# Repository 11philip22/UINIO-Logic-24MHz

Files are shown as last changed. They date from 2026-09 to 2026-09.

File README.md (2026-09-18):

# UINIO-Logic-24MHz Logic Analyzer

[**UINIO-Logic-24MHz**](https://gitee.com/uinika/UINIO-Logic-24MHz) is a logic analyzer circuit design based on Infineon's (formerly Cypress) [**CY7C68013A**](https://www.infineon.com/cms/en/product/universal-serial-bus-usb-power-delivery-controller/peripheral-controllers/ez-usb-fx2lp/cy7c68013a-56ltxit/) `USB 2.0` controller and the [**sigrok**](https://sigrok.org/) open-source firmware. It provides a `24 MHz` sampling rate and **8** input channels.

| Front | Back |
| :---: | :---: |
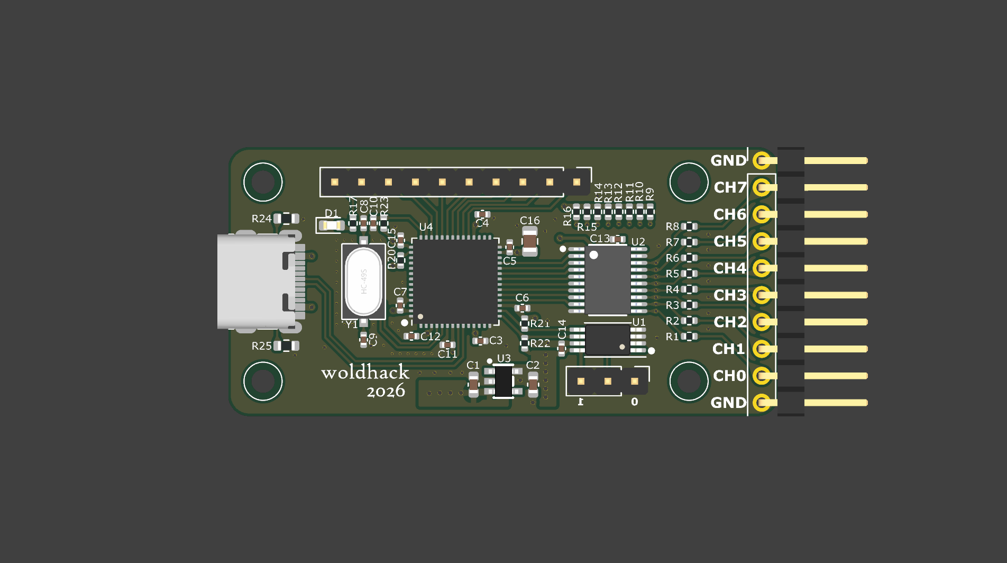
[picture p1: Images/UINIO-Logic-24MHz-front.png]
Front of the UINIO-Logic-24MHz PCB
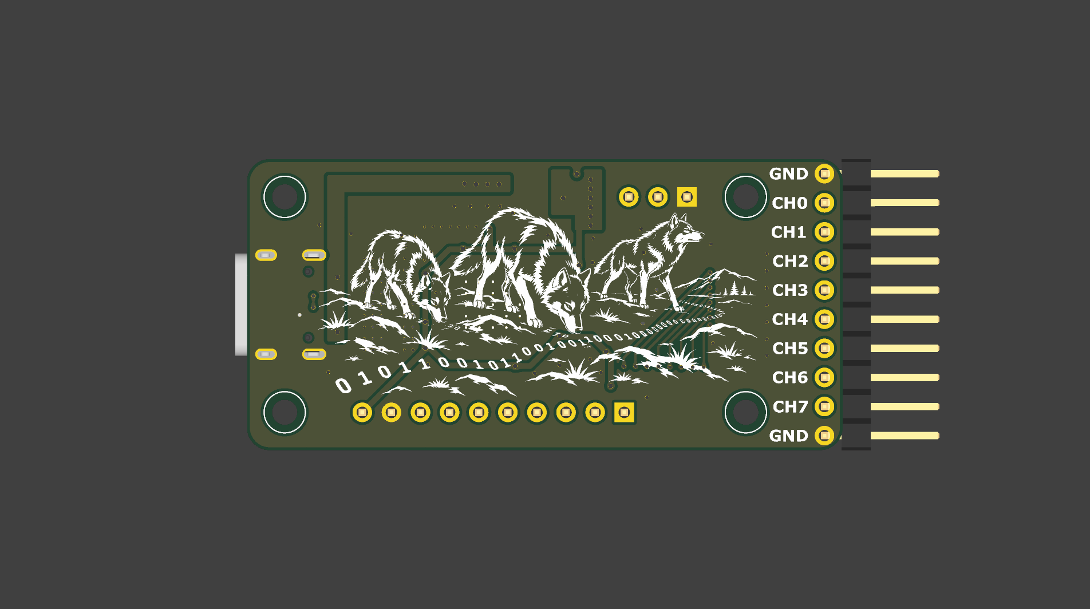
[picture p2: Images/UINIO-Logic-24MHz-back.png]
Back of the UINIO-Logic-24MHz PCB
|  |  |

## Design Overview

1. Uses a **USB Type-C** connector and a `10-pin` shrouded header.
2. The **CY7C68013A** USB controller uses a compact `QFN-56` package.
3. The **AT24C64** EEPROM from Microchip uses a compact `TSSOP-8` package.
4. Includes an onboard `24 MHz` passive SMD crystal; all SMD resistors and capacitors use the compact `0402` package.
5. Adds a **74HC245** eight-channel bus transceiver with **tri-state outputs** for more reliable signal acquisition.
6. The low-dropout regulator can use an **LDO** such as the `ME6211C33M5G` or `A6303AE5R-33A` in an `SOT-23-5` package.
7. Adds a set of TVS diodes for transient-voltage protection at the **USB Type-C** connector.

## Notes

- LED `D2` is connected to the **CY7C68013A** `PA0` pin, while `D3` is connected to `PA1`.
- Use the [sigrok-firmware-fx2lafw](https://github.com/wuxx/sigrok-firmware-fx2lafw) open-source firmware with the [PulseView](https://sigrok.org/wiki/Downloads) desktop application.

## Technical Documentation

[UinIO.com Electronics Technology Lab](http://uinio.com/) provides the following technical resources for the open-source **UINIO-Logic-24MHz** project:

- [UINIO-Logic-24MHz Core Board Schematic](http://uinio.com/my/works/UINIO-Logic-24MHz/UINIO-Logic-24MHz-Schematic.pdf)
- [Interactive BOM and PCB Layout Preview](http://uinio.com/archives/BOM/UINIO-Logic-24MHz.html)
- [UINIO-Logic-24MHz Logic Analyzer Quick Start Guide](http://uinio.com/Project/UINIO-Logic-24MHz/)

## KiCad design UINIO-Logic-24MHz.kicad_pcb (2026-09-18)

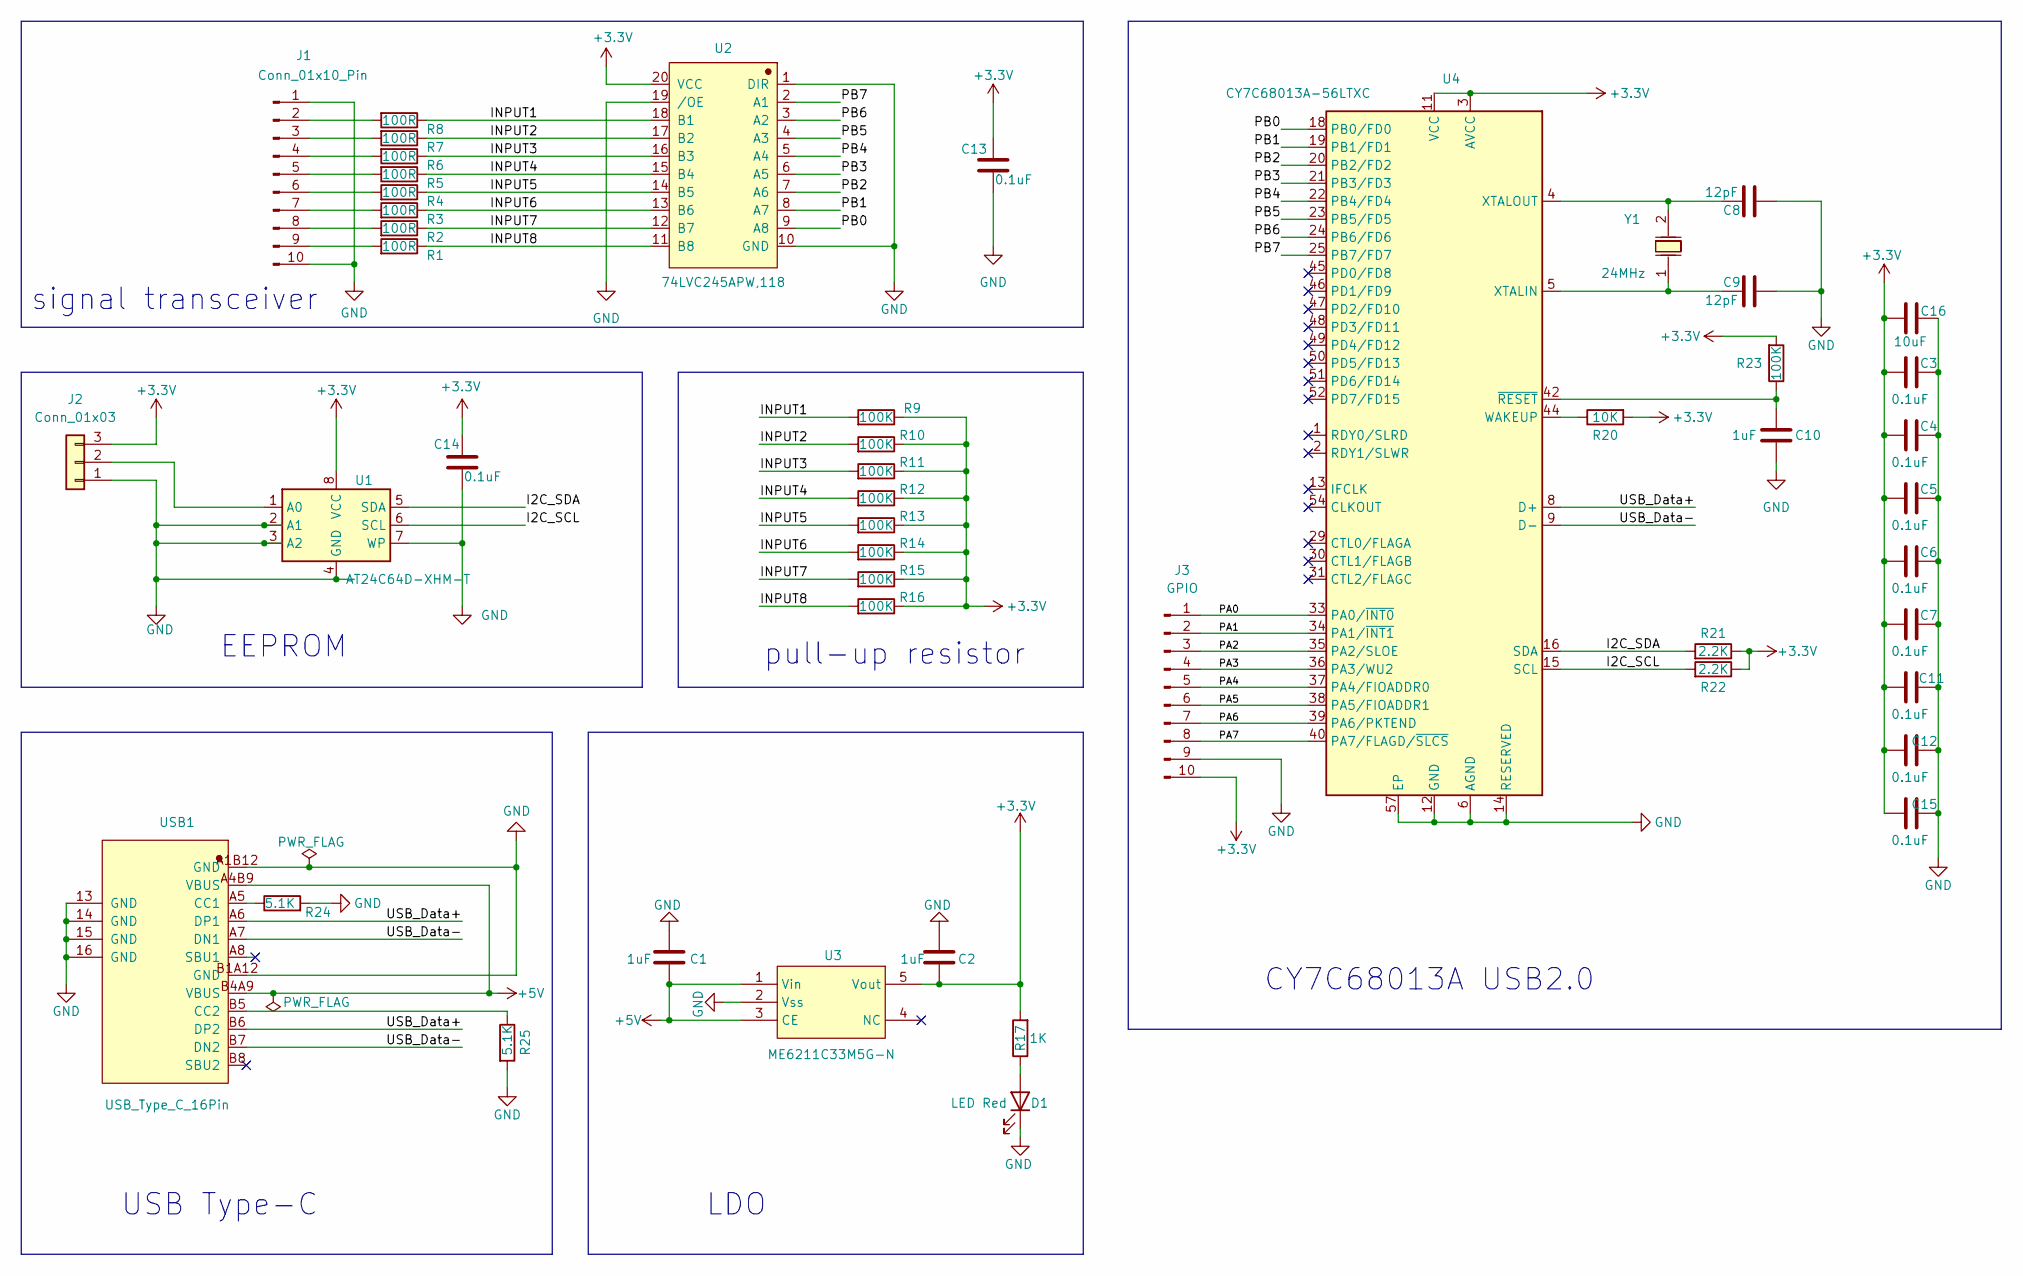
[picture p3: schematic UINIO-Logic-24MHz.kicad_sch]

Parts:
C1, C2: 1uF; C_0603_1608Metric; LCSC Part # C15849
C3, C4, C5, C6, C7, C11, C12, C13, C14, C15: 0.1uF; C_0402_1005Metric; LCSC Part # C1525
C8, C9: 12pF; C_0402_1005Metric; LCSC Part # C1547
C10: 1uF; C_0402_1005Metric; LCSC Part # C52923
C16: 10uF; C_0805_2012Metric; LCSC Part # C15850
D1: LED Red; LED_0603_1608Metric; LCSC Part # C2286
J1: Conn_01x10_Pin; PinHeader_1x10_P2.54mm_Vertical
J2: Conn_01x03; PinHeader_1x03_P2.54mm_Vertical
J3: GPIO; PinHeader_1x10_P2.54mm_Vertical
R1, R2, R3, R4, R5, R6, R7, R8: 100R; R_0402_1005Metric; LCSC Part # C25076
R9, R10, R11, R12, R13, R14, R15, R16, R23: 100K; R_0402_1005Metric; LCSC Part # C25741
R17: 1K; R_0402_1005Metric; LCSC Part # C11702
R20: 10K; R_0402_1005Metric; LCSC Part # C25744
R21, R22: 2.2K; R_0402_1005Metric; LCSC Part # C25879
R24, R25: 5.1K; R_0603_1608Metric; LCSC Part # C23186
U1: AT24C64D-XHM-T; TSSOP-8_4.4x3mm_P0.65mm; LCSC Part # C111440
U2: 74LVC245APW,118; TSSOP-20_L6.5-W4.4-P0.65-LS6.4-BL; LCSC Part # C6082
U3: ME6211C33M5G-N; SOT-23-5_L3.0-W1.7-P0.95-LS2.8-BR; LCSC Part # C82942
U4: CY7C68013A-56LTXC; QFN-56-1EP_8x8mm_P0.5mm_EP4.5x5.2mm_ThermalVias_TopTented; LCSC Part # C14912
USB1: USB_Type_C_16Pin; USB-C-SMD_TYPEC-304J-BCP16; LCSC Part # C2835315
Y1: 24MHz; HC-49-SMD_L7.0-W3.0; MPN X49XM24MOB2SC; LCSC Part # C412889

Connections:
+3.3V: C2.2, C3.1, C4.1, C5.1, C6.1, C7.1, C11.1, C12.1, C13.2, C14.2, C15.1, C16.1, J2.3, J3.10, R9.1, R10.1, R11.1, R12.1, R13.1, R14.1, R15.1, R16.1, R17.2, R20.2, R21.1, R22.1, R23.2, U1.8 (VCC), U2.20 (VCC), U3.5 (Vout), U4.3 (AVCC), U4.7 (AVCC), U4.11 (VCC), U4.17 (VCC), U4.27 (VCC), U4.32 (VCC), U4.43 (VCC), U4.55 (VCC)
+5V: C1.2, U3.1 (Vin), U3.3 (CE), USB1.A4B9 (VBUS), USB1.B4A9 (VBUS)
/I2C_SCL: R22.2, U1.6 (SCL), U4.15 (SCL)
/I2C_SDA: R21.2, U1.5 (SDA), U4.16 (SDA)
/INPUT1: R8.1, R9.2, U2.18 (B1)
/INPUT2: R7.1, R10.2, U2.17 (B2)
/INPUT3: R6.1, R11.2, U2.16 (B3)
/INPUT4: R5.1, R12.2, U2.15 (B4)
/INPUT5: R4.1, R13.2, U2.14 (B5)
/INPUT6: R3.1, R14.2, U2.13 (B6)
/INPUT7: R2.1, R15.2, U2.12 (B7)
/INPUT8: R1.1, R16.2, U2.11 (B8)
/PA0: J3.1, U4.33 (PA0/~INT0)
/PA1: J3.2, U4.34 (PA1/~INT1)
/PA2: J3.3, U4.35 (PA2/SLOE)
/PA3: J3.4, U4.36 (PA3/WU2)
/PA4: J3.5, U4.37 (PA4/FIOADDR0)
/PA5: J3.6, U4.38 (PA5/FIOADDR1)
/PA6: J3.7, U4.39 (PA6/PKTEND)
/PA7: J3.8, U4.40 (PA7/FLAGD/~SLCS)
/PB0: U2.9 (A8), U4.18 (PB0/FD0)
/PB1: U2.8 (A7), U4.19 (PB1/FD1)
/PB2: U2.7 (A6), U4.20 (PB2/FD2)
/PB3: U2.6 (A5), U4.21 (PB3/FD3)
/PB4: U2.5 (A4), U4.22 (PB4/FD4)
/PB5: U2.4 (A3), U4.23 (PB5/FD5)
/PB6: U2.3 (A2), U4.24 (PB6/FD6)
/PB7: U2.2 (A1), U4.25 (PB7/FD7)
/USB_Data+: U4.8 (D+), USB1.A6 (DP1), USB1.B6 (DP2)
/USB_Data-: U4.9 (D-), USB1.A7 (DN1), USB1.B7 (DN2)
GND: C1.1, C2.1, C3.2, C4.2, C5.2, C6.2, C7.2, C8.1, C9.1, C10.1, C11.2, C12.2, C13.1, C14.1, C15.2, C16.2, D1.1 (K), J1.1, J1.10, J2.1, J3.9, R24.2, R25.2, U1.2 (A1), U1.3 (A2), U1.4 (GND), U1.7 (WP), U2.1 (DIR), U2.10 (GND), U2.19 (/OE), U3.2 (Vss), U4.6 (AGND), U4.10 (AGND), U4.12 (GND), U4.14 (RESERVED), U4.26 (GND), U4.28 (GND), U4.41 (GND), U4.53 (GND), U4.56 (GND), U4.57 (EP), USB1.13 (GND), USB1.14 (GND), USB1.15 (GND), USB1.16 (GND), USB1.A1B12 (GND), USB1.B1A12 (GND)
unnamed: D1.2 (A), R17.1
unnamed: J1.2, R8.2
unnamed: J1.3, R7.2
unnamed: J1.4, R6.2
unnamed: J1.5, R5.2
unnamed: J1.6, R4.2
unnamed: J1.7, R3.2
unnamed: J1.8, R2.2
unnamed: J1.9, R1.2
unnamed: J2.2, U1.1 (A0)
unnamed: R20.1, U4.44 (WAKEUP)
unnamed: C9.2, U4.5 (XTALIN), Y1.1 (OSC1)
unnamed: C8.2, U4.4 (XTALOUT), Y1.2 (OSC2)
unnamed: C10.2, R23.1, U4.42 (~RESET)
unnamed: R24.1, USB1.A5 (CC1)
unnamed: R25.1, USB1.B5 (CC2)

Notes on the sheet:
CY7C68013A USB2.0
LDO
signal transceiver
pull-up resistor
USB Type-C
EEPROM

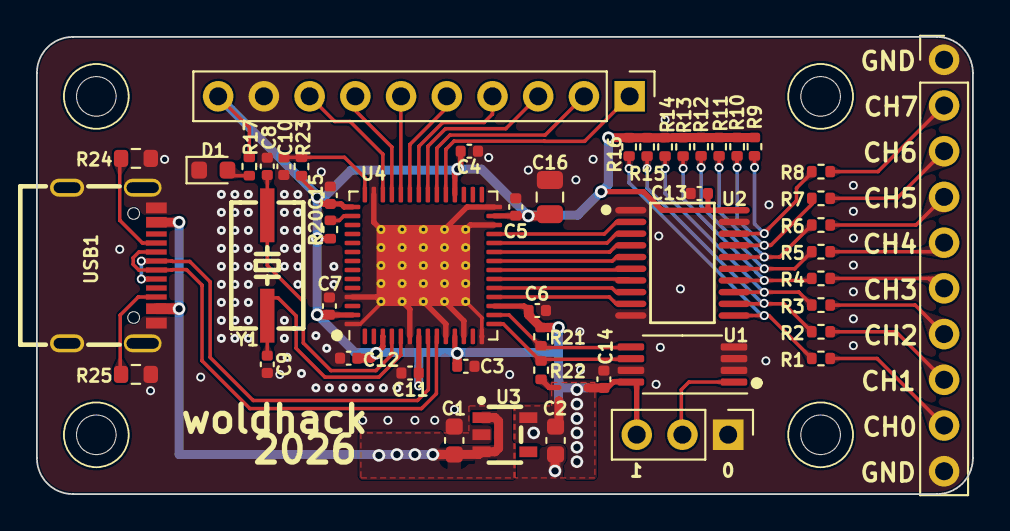
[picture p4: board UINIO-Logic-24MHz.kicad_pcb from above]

Board: 2 copper layers, 52.0 x 25.4 mm, 53 parts (0 on the bottom side), 47 nets.

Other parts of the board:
HOLE1, HOLE2, HOLE3, HOLE4: Hole-2mm

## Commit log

2026-09-04 chore: update parts
    [UINIO-Logic-24MHz.kicad_pcb, UINIO-Logic-24MHz.kicad_sch]
2026-09-16 feat: update silkscreen
    [UINIO-Logic-24MHz-B_Cu.gbl, UINIO-Logic-24MHz-B_Mask.gbs, UINIO-Logic-24MHz-B_Paste.gbp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]
2026-09-17 fix: production check
    [UINIO-Logic-24MHz.kicad_pcb, UINIO-Logic-24MHz.kicad_sch]
